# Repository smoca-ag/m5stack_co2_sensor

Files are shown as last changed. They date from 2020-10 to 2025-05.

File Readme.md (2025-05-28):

# Build your own portable, graphing CO₂ sensor

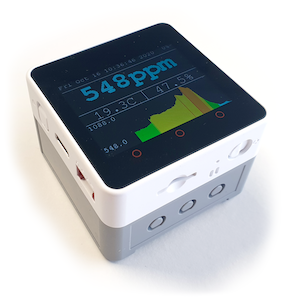
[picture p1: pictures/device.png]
Device The Device


## Motivation

CO₂ levels measured indoors can be used as an indicator of air quality.

Outdoor air has a CO₂ ppm level of 400 ppm. Humans exhale air with 40000 ppm. You can calculate the percentage of exhaust air you are breathing by dividing measured CO₂ level above outdoor by the human exhaust level. Used air might contain aerosols which might contain the corona virus.

High indoor CO₂ levels also have an impact on the cognitive performance of humans.

Smoca AG decided to build this easy to reproduce CO₂ measuring device to help slow the spread of the corona virus in offices.
It supports its users in deciding when ventilating the room begin monitored is advisable. It also raises awareness for the correlation between CO₂ level and air quality.

## Hardware

The following hardware is needed:

| description | cost | link |
| --- | --- | --- |
| Sensirion SCD30 | 54 USD | https://www.digikey.com/en/products/detail/sensirion-ag/SCD30/8445334<br>Switzerland: https://www.bastelgarage.ch/co2-sensor-scd30-sensirion |
| M5 Stack Core2 | 39.9 USD | https://www.digikey.com/en/products/detail/m5stack-technology-co-ltd/K010/13151126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<br>Switzerland: https://www.bastelgarage.ch/m5stack-core2-esp32-iot-entwicklungs-kit |
| M5 Stack Proto Board | 2.95 USD | https://www.digikey.com/en/products/detail/m5stack-technology-co-ltd/M001/10492145<br>Switzerland: https://www.bastelgarage.ch/m5stack-core-development-proto-board |
| M5 Stack PLC Base | 9.95 USD | https://m5stack.com/collections/m5-base/products/plc-proto-industrial-board-module<br>Switzerland: https://www.bastelgarage.ch/m5stack-plc-proto-base-industrial-board |
| M5 Stack Battery (optional) | 7.95 USD | https://www.digikey.com/en/products/detail/m5stack-technology-co-ltd/M002/10492127<br>Switzerland: https://www.bastelgarage.ch/m5stack-battery-module-700mah-fur-esp32-core |

Note: The optional battery increases the battery operation time from 6 to 10 hours.

### Building

|Description | Image
|--- | ---
|1. Power the Core2 module. A factory test application should be loaded. Test the device. |
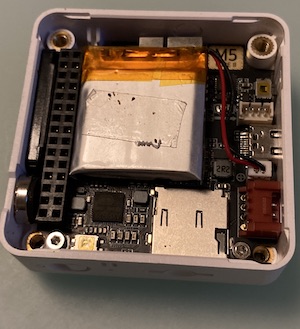
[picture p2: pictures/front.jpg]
Front
|2. Remove the bottom of the Core2 module. Keep the battery there or replace it with the optional bigger one. | 
|3. Remove the PCB from the proto module. |
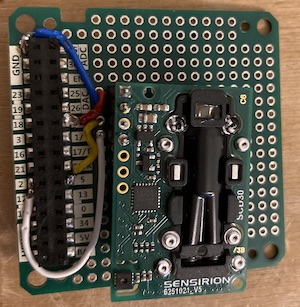
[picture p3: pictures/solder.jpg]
solder
|4. Connect the SCD30 module to the proto module. We used pin headers. | 
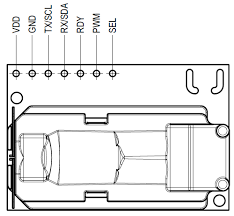
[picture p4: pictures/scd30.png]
scd30
|5. Connect VDD with 3V3, GND with GND, TX/SCL with pin 5 and RX/SDA with pin 2. The other pins don't need to be connected to the proto module. | 
|5. Screw the proto module to the PLC Base |
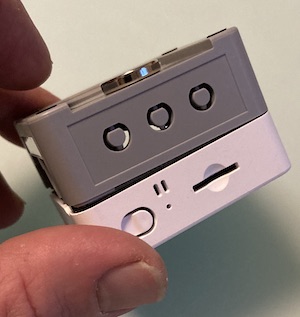
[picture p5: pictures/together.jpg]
together connected
|6. Screw the PLC Base to the Core2 module | 
|7. HW Done, load the software |

## Software

To initialise the device do the following:

1. Install [Platformio IDE](https://platformio.org/platformio-ide) or [PlatformIO Core](https://docs.platformio.org/en/latest/core/installation.html) to use another IDE
2. Open the `co2-sensor` project folder
3. Flash the `main.cpp` script to your M5 Stack Core2 with `pio run -t upload --upload-port {your_device}`. You can see a list of your devices with `pio device list`. Dependencies are installed automatically.

## Features

#### Calibration

The SCD30 can be calibrated manually or automatically. For manual calibration, the device must be placed outdoors for at least five minutes. Then the calibration can be adjusted. Fresh air has a CO₂ concentration of about 400 ppm. To use automatic calibration, the device must have access to fresh air for at least one hour a day.

#### WiFi

To use MQTT, synchronization and update functionality the device must have internet connection. To add WiFi credentials the device opens an access point with a web interface (Default IP is 192.168.4.1). 

#### Data sharing via MQTT

[MQTT](https://mqtt.org/) can be used to send the sensors data to a custom MQTT broker. Server, Port, Topic, Device name, Username and Password can also be configured in the web interface. Each minute the device sends its data in the following format: `{TOPIC}/{CATEGORY} {VALUE}`. Here an example: `sensor/co2 650`.  
Topics are able to have subtopics: `office2/meeting_room1/co2 1100`.  
The following categories are provided by the device: `/co2`, `/humidity`, `/temperature`.

#### Time synchronization

To keep time up to date the device synchronizes with a time server each night between two and three o'clock.

#### Firmware updates

Is a new firmware available, it can manually be updated via WiFi.

#### SNMP

Using SNMP you are able to read the values of the co2, temperature and humidity sensors and also check the battery status of the device:
1. First you have to make sure you have net-snmp installed on your system. You can do this using your package manager or by downloading it from http://www.net-snmp.org/download.html
2. Second you have to find out where your mib files are stored using the command ```net-snmp-config --default-mibdirs```.
3. Then you have to copy the [mib file](./snmp-mib/sensorhub.mib) from ```/snmp-mib/sensorhub.mib``` into one of the listed directories. e.g. ```cp snmp-mib/sensorhub.mib ~/.snmp/mibs```
4. Done that, you can now use snmptable to list the sensors: 
    ```snmptable -m +SENSORHUB-MIB -c public {IP-Address} shSensorTable```
    \
    Which should output the following:
    ```
    SNMP table: SENSORHUB-MIB::shSensorTable

    shSensorName
            SCD30
            BATTERY
   ```
    or to list the measurement values: 
    ```snmptable -m +SENSORHUB-MIB -c public {IP-Address} shMeasurementTable```
    \
    Which should output something like this:
    ```
    SNMP table: SENSORHUB-MIB::shMeasurementTable

    shMeasurementType shMeasurementValue
                co2                  617
        temperature                  207
           humidity                  433
            voltage                  3
    electricCurrent                  276
   ```

## Usage

**Disclaimer This is not a safety device. Always follow the local regulations regarding corona safety. No warranty is provided**
![Device](pictures/flyer.png "Device usage")

### Graphs

- The graphs alway show the last six hours. Every line on the graph represents the measurement of one minute. The last value measured in the given minute is used for the graph.
- To switch between different graphs (temperature / humidity / battery / co2) touch the corresponding value in the display

### microsd

If a microsd card formated with fat is present, a csv file, data.txt will be written every 2 seconds with the timestamp, the co2 level, the humidity, the temperature and the current battery charge.

### CO₂

| level           | color  | description                                                                                               |
| --------------- | ------ | --------------------------------------------------------------------------------------------------------- |
| < 600 ppm       | blue   | outdoor air                                                                                               |
| 600 - 800 ppm   | green  | fresh indoor air                                                                                          |
| 800 - 1000 ppm  | yellow | indoor air, ventilate the room if possible, small possibility of virus transmission                       |
| 1000 - 1400 ppm | orange | used indoor air, ventilate the room, cognition is impacted, possibility of virus transmission             |
| > 1400 ppm      | red    | heavy used indoor air, heavy cognition impact, high possiblity of virus transmission, ventilation needed. |

## Extended uses (no code provided)

- We use it at our office to control a couple of exhaust / inlet pwm computer fans to keep the CO₂ level below 800 ppm.
- We log the measurement results to a influxdb with a grafana dashboard. The grafana instance sends alerts to telegram for CO₂ levels above 800 ppm.

## SCD4x
There is a PCB in the PCB folder for SCD41 Support. The Code Supports transparently SCD40 and SCD30 at the moment.

## Contact

If you have any suggestions for the project feel free to file an issue. If you want to build the device on a bigger scale / have any other development / prototyping needs, feel free to contact us: info@smoca.ch

## License

Copyright (c) 2020 David Gunzinger / smoca AG www.smoca.ch \
Code: GPL v3 \
Text / Graphics / Photographs: CC BY-SA

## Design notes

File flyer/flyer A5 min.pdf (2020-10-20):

# PORTABLE GRAPHING

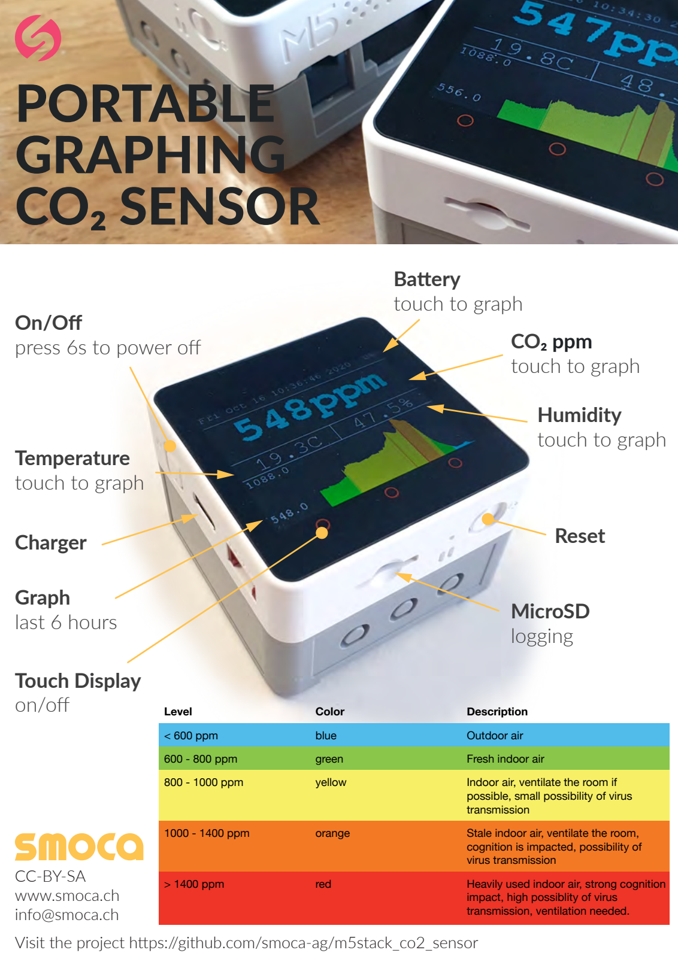
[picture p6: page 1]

# CO₂ SENSOR

## On/Off

## press 6s to power off

## Battery

## touch to graph

## CO₂ ppm

## touch to graph

## Temperature

## touch to graph

## Charger

## Humidity

## touch to graph

## Touch Display

## on/off

## Reset

## MicroSD

## logging

## Graph

## last 6 hours

### Visit the project https://github.com/smoca-ag/m5stack_co2_sensor

### CC-BY-SA www.smoca.ch info@smoca.ch

Level | Color | Description
< 600 ppm | blue | Outdoor air
600 - 800 ppm | green | Fresh indoor air
800 - 1000 ppm | yellow | Indoor air, ventilate the room if possible, small possibility of virus transmission
1000 - 1400 ppm | orange | Stale indoor air, ventilate the room, cognition is impacted, possibility of virus transmission
> 1400 ppm | red | Heavily used indoor air, strong cognition impact, high possiblity of virus transmission, ventilation needed.

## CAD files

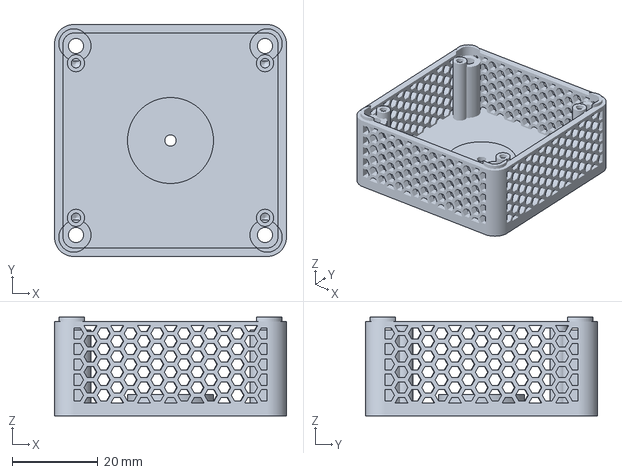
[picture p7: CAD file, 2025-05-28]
case/encasing3-Cut.3mf
54.0 x 54.0 x 23.0 mm

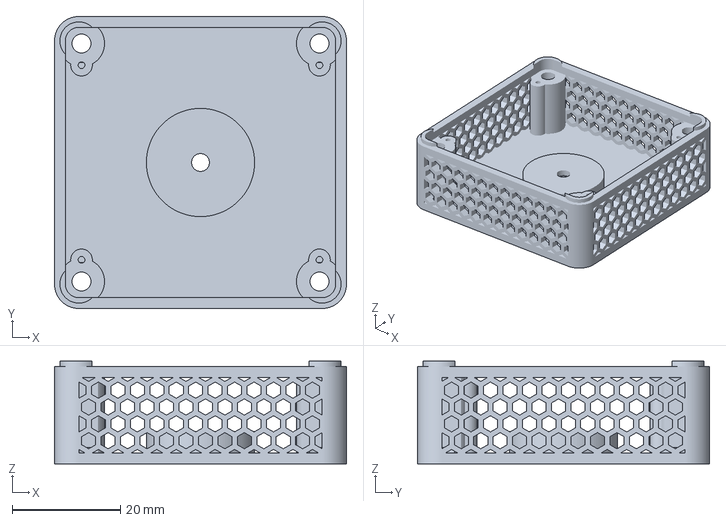
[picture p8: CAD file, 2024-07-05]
case/encasing4-Cut.3mf
54.0 x 54.0 x 19.0 mm

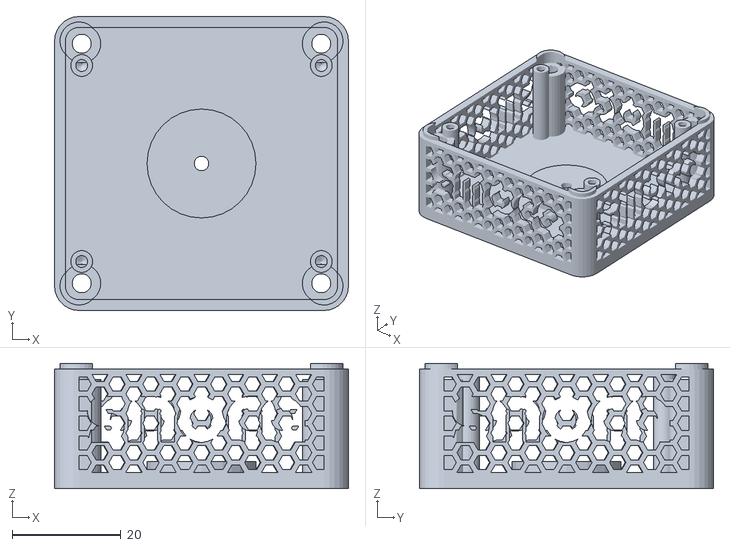
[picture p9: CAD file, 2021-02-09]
case/encasing3_smoca_body.stl
54.0 x 54.0 x 23.0

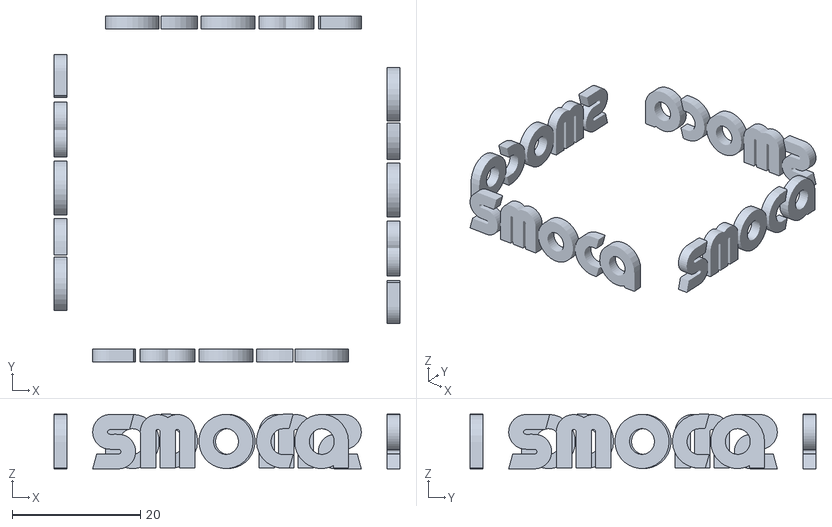
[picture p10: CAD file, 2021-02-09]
case/encasing3_smoca_color.stl
54.0 x 54.0 x 8.55

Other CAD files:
case/encasing4.FCStd
case/encasing3.stl
case/encasing4-Cut.stl

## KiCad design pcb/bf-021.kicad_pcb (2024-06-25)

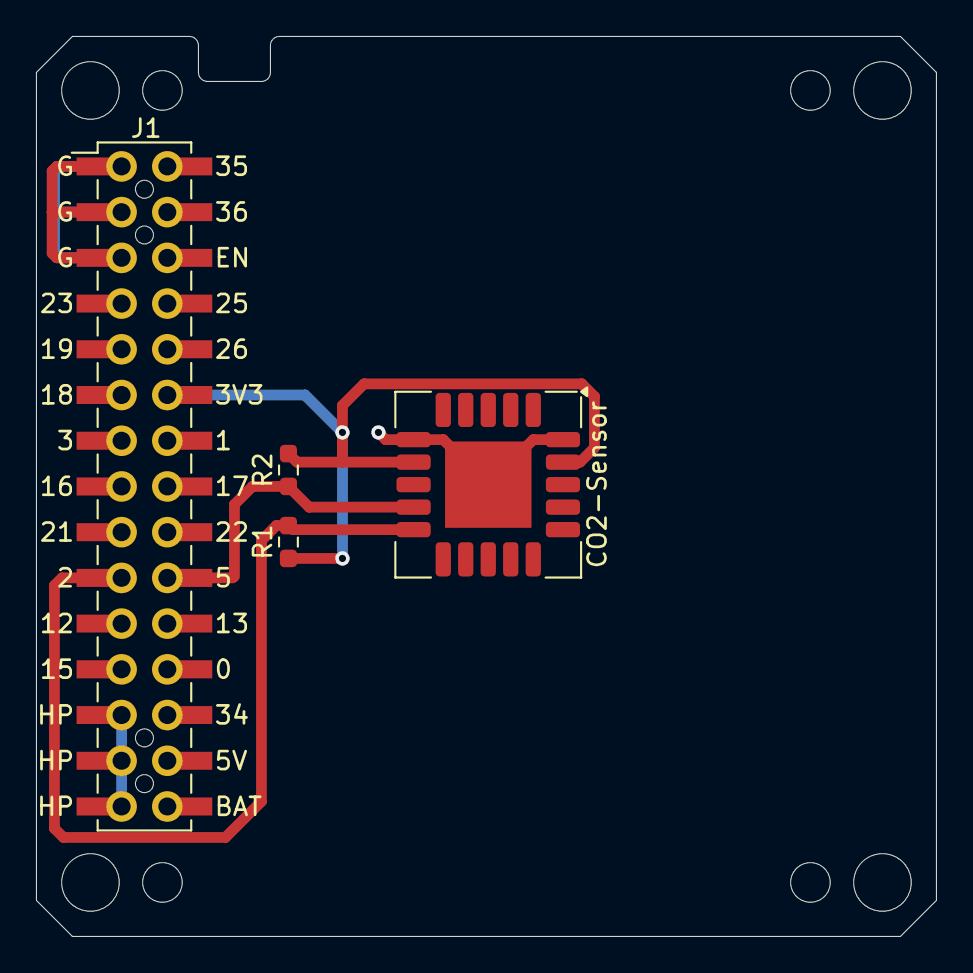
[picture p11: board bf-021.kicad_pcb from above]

Board: 2 copper layers, 50.0 x 50.0 mm, 12 parts (0 on the bottom side), 4 nets.

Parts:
CO2-Sensor: SCD40-D-R2; Sensirion_SCD4x-1EP_10.1x10.1mm_P1.25mm_EP4.8x4.8mm
H1, H2, H3, H4: MountingHole; BF@MountingHole_3.2mm_M3
H5, H6, H7, H8: MountingHole; BF@MountingHole_2.2mm_M2
J1: M-BUS; BF@M5Stack_MBUS
R1, R2: 10k; R_0603_1608Metric_Pad0.98x0.95mm_HandSolder

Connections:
+3V3: CO2-Sensor.7 (VDD), CO2-Sensor.19 (VDD), J1.11, R1.1, R2.2
GND: CO2-Sensor.6 (GND), CO2-Sensor.20 (GND), CO2-Sensor.21 (GND), J1.2, J1.4, J1.6
SDA: CO2-Sensor.9 (SCL), CO2-Sensor.10 (SDA), J1.19, J1.20, R1.2, R2.1
VBUS: J1.26, J1.28, J1.30

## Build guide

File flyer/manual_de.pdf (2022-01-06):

## CO₂ SENSOR Bedienungsanleitung

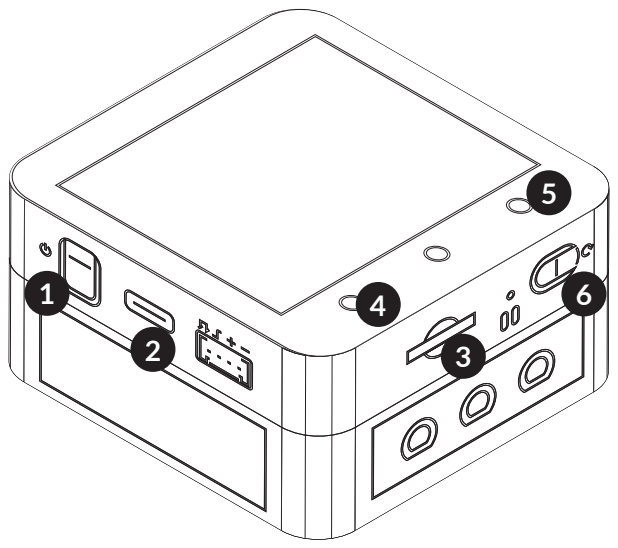
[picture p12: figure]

AN/AUS
Drücken Sie den Knopf 6 Sekunden um das Gerät auszuschalten

LADEN (USB-C)
Laden Sie das Gerät mit dem mitgeliefertem USB Ladekabel oder einem andern kompatiblem USB-C Kabel

MICRO SD-CARD (LOGGING)
Legen Sie eine im FAT formatierte Micro-SD Karte ein um die CO₂ Konzentration-Daten alle 2 Sekunden aufzuzeichnen. Wahlweise wird eine CSV- oder TXT-Datei erstellt.

HOME
Gelangen Sie ins Hauptmenü. Das Display kann hier ausgeschaltet werden.

NAVIGATION
Navigiert durch das Menu

RESET
Startet das System neu.

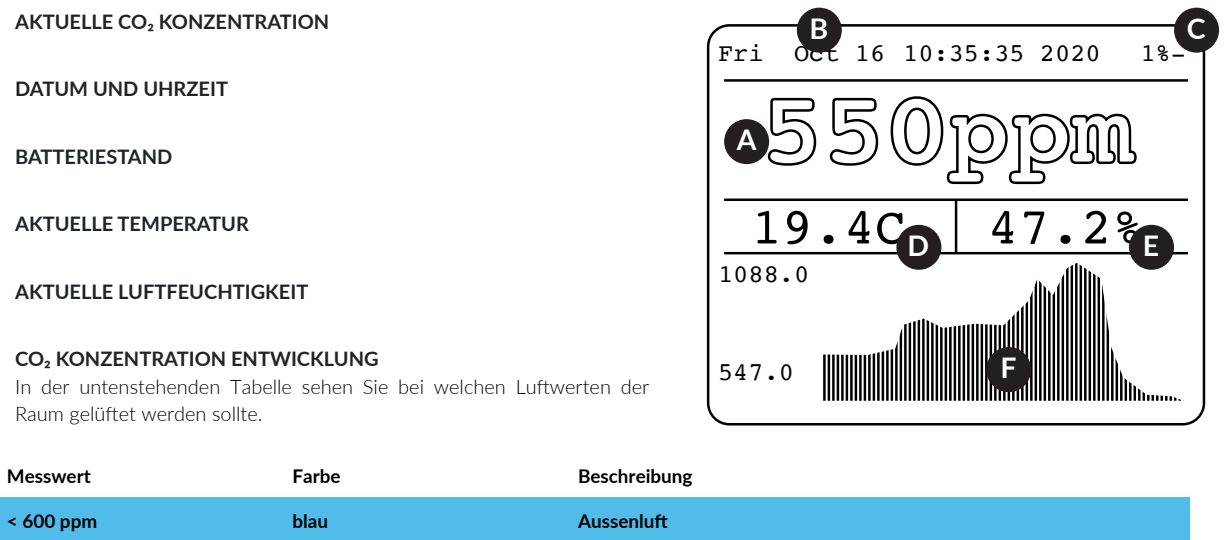
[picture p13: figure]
AKTUELLE CO₂ KONZENTRATION; DATUM UND UHRZEIT; BATTERIESTAND; AKTUELLE TEMPERATUR; AKTUELLE LUFTFEUCHTIGKEIT; CO₂ KONZENTRATION ENTWICKLUNG; Raum gelüftet werden sollte.; Fri Oct 16 10:35:35 2020; 550ppm; Messwert; Farbe; Beschreibung; < 600 ppm; blau; Aussenluft

In der untenstehenden Tabelle sehen Sie bei welchen Luftwerten der

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
KALIBRIEREN
Vor Inbetriebnahme ist es nötig das Gerät zu kalibrieren. Drücken Sie auf den HOME (4) Knopf und wählen Sie eine automatische oder manuelle Kalibration aus:

Automatisch (empfohlen)
Stellen Sie das Gerät täglich für 1h an die frische Luft.
Manuell
Stellen Sie das Gerät für 5min an die frische Luft. Die Kalibration kann manuell mit den Bedienelementen erhöht oder verringert werden. Frischluft hat eine CO₂ Konzentration von ca 400 ppm.
600 - 800 ppm | grün | Frische Innenluft
800 - 1000 ppm | gelb | Innenluft. Raum lüften wenn möglich. Kleine Wahrscheinlichkeit für Virusübertragung.
1000 - 1400 ppm | orange | Abgestandene Innenluft. Raum lüften. Denkleistung wird beeinträchtigt. Virusübertragung möglich.
> 1400 ppm | rot | Stark gebrauchte Innenluft. Lüften notwendig. Hohe Beeinträchtigung der Denkleistung. Hohe Wahrscheinlichkeit für Virusübertragung.

Weitere Informationen unter: https://www.smoca.ch/produkte/co2sensor oder info@smoca.ch Github: https://github.com/smoca-ag/m5stack_co2_sensor

©2021 Smoca AG
Lizenz: Creative Commons BY-SA Der Sensor wurde entwickelt und zur Verfügung gestellt von smoca AG.

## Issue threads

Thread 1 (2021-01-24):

Request for Soldering schematics / wiring diagram

tolkiman, 2021-01-24:
Step 4 simply states "Connect the SCD30 module to the proto module. We used headers."

I would really like to build this project, however its hard to make out which connections to solder and what to connect exactly. Would you be able to supply a simple wiring diagram / soldering schematics? Thanks!

4nd2in, 2021-01-25:
On page of the [datasheet](https://cdn.sparkfun.com/assets/1/a/7/9/9/Sensirion_CO2_Sensors_SCD30_Preliminary-Datasheet.pdf) 6 you can see the pin-out diagram of the scd30. You need to connect VDD with 3V3, GND with GND, TX/SCL with pin 5 and RX/SDA with pin 2. The other pins don't need to be connected to the proto module.

tolkiman, 2021-01-26:
Fantastic, thanks for the support!

Closed 2021-01-26.

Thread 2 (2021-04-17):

Too heavy SW

Kabron287, 2021-04-17:
Your project does not work. How to threw out WiFiManager, MQTT, WEB and all this trash and leave only essential.

> M5Core2 initializing...axp: vbus limit off
axp: gpio1 init
axp: gpio2 init
axp: rtc battery charging enabled
axp: esp32 power voltage was set to 3.35v
axp: lcd backlight voltage was set to 2.80v
axp: lcd logic and sdcard voltage preset to 3.3v
axp: vibrator voltage preset to 2v
touch: FT6336 ready (fw id 0x10 rel 1, lib 0x300E)
OK
Loaded state file.
deserializeJson() failed: InvalidInput
cgw4Q9da
Setting time: Fri Jun 30 20:49:34 2000
The current date/time in Zuerich is: Fri Jun 30 22:49:34 2000Initializing SD card...
File already exists
WiFi off status: 6
Failed to obtain time
we are to slow:5019
Message appended
Guru Meditation Error: Core  1 panic'ed (StoreProhibited). Exception was unhandled.

Kabron287, 2021-04-17:
Problem was in my sensor driver.
I use  T6703.

pfy, 2021-04-17:
Hi

The NTP Code has a bug as well. If the device does not have the correct time, it might busy loop the ntp code. The we are to slow:5019 message confirms this -> we will push an update next week.

isn't the T6703 more expensive than the sensirion part ? The sensirion costs about 50 CHF and the T6703 about 100 CHF ?

best regards

David Gunzinger
CTO, Co-Founder

Smoca AG ǀ Technoparkstrasse 2 ǀ 8406 Winterthur
G: +41 52 508 59 57
M: ***@***.***
W: www.smoca.ch

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

Kabron287, 2021-04-17:
Thanks for answer/
About 25 CHF on aliexpress.

Closed 2021-04-17.

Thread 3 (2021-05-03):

Make battery size configurable

tobru, 2021-05-03:
When using the bigger battery the display of the available battery percentage isn't calculated correctly. Therefore it would make sense to be able to configure the battery size.

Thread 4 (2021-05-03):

Support MQTT TLS connection

tobru, 2021-05-03:
MQTT can currently only be used with plain TCP connection. My MQTT broker is only reachable via TLS (port 8883). It would be cool if this project would support MQTT TLS connections.

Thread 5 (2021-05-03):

Parts ordering via bastelgarage.ch

tobru, 2021-05-03:
This issue is a FYI issue, can be closed any time: The parts needed for this project are available at bastelgarage.ch, which is easy for Swiss people. Maybe you want to link to it from the README. Disclaimer: I'm not affiliated with bastelgarage.ch, just a fan of them (and this project).

AlfMueller, 2021-08-13:
This issue is a FYI issue, can be closed any time:
add Link for 3d Print Backcover sourcefile on thingiverse:
https://www.thingiverse.com/thing:4651700

marcelstoer, 2021-08-14:
This is actually OT but @AlfMueller did you find the case on Thingiverse more useful then the one in this repository at https://github.com/smoca-ag/m5stack_co2_sensor/blob/main/case/encasing3.stl?

Closed 2021-08-14.

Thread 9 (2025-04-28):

Support the SCD4x sensors

marcelstoer, 2025-04-28:
(This is a kind-of note to self as I plan on adding this)

Support the SCD4x sensors by using their official driver from https://registry.platformio.org/libraries/sensirion/Sensirion%20I2C%20SCD4x

pfy, 2025-05-28:
we already did that and even have a sample pcb inside the pcb folder. Please Note: The magnet seems to interfere with the mems microphone inside the SCD40, especially during attaching and detaching.

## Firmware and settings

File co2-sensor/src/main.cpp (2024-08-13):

/*
 * This file is part of the co2sensor distribution (https://github.com/xxxx or http://xxx.github.io).
 * Copyright (c) 2020 David Gunzinger / smoca AG.
 *
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
 * You should have received a copy of the GNU General Public License
 * along with this program. If not, see <http://www.gnu.org/licenses/>.
 */

#include <main.h>
#include <lwip/apps/snmp.h>
#include <sensorhub-mib.h>

static const struct snmp_mib *mibs[] = {
    &sensorhub_mib};

struct state state;
struct graph graph;

// background, text, outline
ButtonColors offWhite = {BLACK, WHITE, WHITE};
ButtonColors onWhite = {WHITE, BLACK, WHITE};
ButtonColors offCyan = {BLACK, CYAN, CYAN};
ButtonColors onCyan = {CYAN, BLACK, CYAN};
ButtonColors offRed = {BLACK, RED, RED};
ButtonColors onRed = {RED, BLACK, RED};
ButtonColors offGreen = {BLACK, GREEN, GREEN};
ButtonColors onGreen = {GREEN, BLACK, GREEN};

// x, y, w, h, rot, txt, off col, on color, txt pos, x-offset, y-offset, corner radius
Button batteryButton(240, 0, 80, 40);
Button co2Button(0, 26, 320, 88);

Button midLeftButton(-2, 104, 163, 40, false, "midLeft", offWhite, onWhite, BUTTON_DATUM, 0, 0, 0);
Button midRightButton(161, 104, 164, 40, false, "midRight", offWhite, onWhite, BUTTON_DATUM, 0, 0, 0);

Button toggleAutoCalButton(15, 175, 130, 50, false, "Auto Cal: OFF", offRed, onRed);
Button submitCalibrationButton(175, 175, 130, 50, false, "Calibrate", offCyan, onCyan);

Button toggleWiFiButton(15, 175, 130, 50, false, "OFF", offRed, onRed);
Button resetWiFiButton(175, 175, 130, 50, false, "Reset", offCyan, onCyan);

Button syncTimeButton(15, 175, 290, 50, false, "Sync Time", offCyan, onCyan);
Button rotateScreenButton(15, 175, 290, 50, false, "Rotate", offCyan, onCyan);

TFT_eSprite DisbuffHeader = TFT_eSprite(&M5.Lcd);
TFT_eSprite DisbuffValue = TFT_eSprite(&M5.Lcd);
TFT_eSprite DisbuffGraph = TFT_eSprite(&M5.Lcd);
TFT_eSprite DisbuffBody = TFT_eSprite(&M5.Lcd);

uint64_t chipid = ESP.getEfuseMac(); // The chip ID is essentially its MAC address(length: 6 bytes).
uint16_t chip = (uint16_t)(chipid >> 32);


String ssid = "smoca CO2-" + String(chip, HEX) + String((uint32_t)chipid, HEX);
IPAddress stationIP = IPAddress(0, 0, 0, 0);
IPAddress gatewayIP = IPAddress(192, 168, 2, 1);
IPAddress netMask = IPAddress(255, 255, 255, 0);

IPAddress dns1IP = gatewayIP;
IPAddress dns2IP = IPAddress(8, 8, 8, 8);

IPAddress APStaticIP = IPAddress(192, 168, 100, 1);
IPAddress APStaticGW = IPAddress(192, 168, 100, 1);
IPAddress APStaticSN = IPAddress(255, 255, 255, 0);

AsyncWebServer webServer(80);

SCD30 airSensorSCD30;
SCD4x airSensorSCD40;
void* currentAirSensor;

WM_Config WM_config;
WiFi_STA_IPConfig WM_STA_IPconfig;

AsyncDNSServer dnsServer;
String Router_SSID;
String Router_Pass;

ESPAsync_WiFiManager *asyncWifiManager;

ESPAsync_WMParameter *mqttServer;
ESPAsync_WMParameter *mqttPort;
ESPAsync_WMParameter *mqttTopic;
ESPAsync_WMParameter *mqttDevice;
ESPAsync_WMParameter *mqttUser;
ESPAsync_WMParameter *mqttPassword;

WiFiClient client;
PubSubClient mqtt(client);

// MQTT discovery data configurations
struct discoveryDeviceConfig deviceConfig;
struct discoveryConfig co2Config;
struct discoveryConfig humidityConfig;
struct discoveryConfig temperatureConfig;
struct discoveryConfig batteryConfig;

// MQTT Discovery unique identifiers
String identifier = String(chip, HEX) + String((uint32_t)chipid, HEX);
String co2DiscoveryIdentifier = identifier + "-1";
String humidityDiscoveryIdentifier = identifier + "-2";
String temperatureDiscoveryIdentifier = identifier + "-3";
String batteryDiscoveryIdentifier = identifier + "-4";
String identifiers =
    co2DiscoveryIdentifier + ", " +
    humidityDiscoveryIdentifier + ", " +
    temperatureDiscoveryIdentifier + ", " +
    batteryDiscoveryIdentifier;

// statistics
unsigned long cycle;
int target_fps = 20;
int frame_duration_ms = 1000 / target_fps;
float my_nan;

void setup()
{
    Serial.println("Start Setup.");
    my_nan = sqrt(-1);

    M5.begin();

    // Initialize SPIFFS
    if (!SPIFFS.begin(true))
    {
        Serial.println("An Error has occurred while mounting SPIFFS");
        return;
    }

    loadStateFile();
    if (state.is_screen_rotated)
    {
        M5.BtnA.set(10, -40, 110, 40, false);
        M5.BtnB.set(130, -40, 70, 40, false);
        M5.BtnC.set(230, -40, 80, 40, false);
        M5.Lcd.setRotation(3);
    }

    M5.Lcd.setSwapBytes(true);
    M5.Lcd.pushImage(96, 96, 128, 32, smoca_logo);

    M5.Axp.SetCHGCurrent(AXP192::kCHG_280mA);
    M5.Axp.EnableCoulombcounter();
    M5.Axp.SetLed(M5.Axp.isACIN() ? 1 : 0);

    ssid.toUpperCase();
    mqtt.setBufferSize(512);

    loadMQTTConfig();
    setPassword(&state);
    setDisplayPower(true);
    setTimeFromRtc();
    printTime();
    createSprites();
    hideButtons();

    if (!state.next_time_sync.tm_year)
    {
        state.next_time_sync.tm_year = 1900;
        state.next_time_sync.tm_hour = TIME_SYNC_HOUR;
        state.next_time_sync.tm_min = TIME_SYNC_MIN;
    }

    for (int i = 0; i < GRAPH_UNITS; i++)
    {
        graph.temperature[i] = my_nan;
        graph.co2[i] = my_nan;
        graph.humidity[i] = my_nan;
        graph.batteryMah[i] = my_nan;
    }

    initSD();
    initAirSensor();
    initAsyncWifiManager(&state);
    initSTAIPConfigStruct(WM_STA_IPconfig);
    initDeviceDiscoveryConfig(&deviceConfig);
    initCo2DiscoveryConfig(&co2Config);
    initHumidityDiscoveryConfig(&humidityConfig);
    initTemperatureDiscoveryConfig(&temperatureConfig);
    initBatteryDiscoveryConfig(&batteryConfig);

    if (mqtt.connected()) {
        sendMQTTDiscoveryMessages(
            &co2Config,
            &humidityConfig,
            &temperatureConfig,
            &batteryConfig
        );
    }

#if LWIP_SNMP
    const struct snmp_obj_id device_enterprise_oid = {8, {1, 3, 6, 1, 4, 1, 58049, 1}};
    snmp_set_device_enterprise_oid(&device_enterprise_oid);

    snmp_set_mibs(mibs, LWIP_ARRAYSIZE(mibs));
    snmp_init();
#endif /* LWIP_SNMP */

    cycle = 0;
    Serial.print(state.is_wifi_activated ? "WiFi on" : "WiFi off");
    Serial.println(" status: " + (String)WiFi.status());
}

extern "C" int get_measurement(u32_t sensor_id, u32_t measurement_type)
{
    switch (sensor_id)
    {
    case 1:
        switch (measurement_type)
        {
        case CO2_PPM_MEASUREMENT:
            return state.co2_ppm;
        case TEMPERATURE_MEASUREMENT:
            return state.temperature_celsius;
        case HUMIDITY_MEASUREMENT:
            return state.humidity_percent;
        default:
            return 0;
        }
        break;
    case 2:
        switch (measurement_type)
        {
        case BATTERY_VOLTAGE_MEASUREMENT:
            return state.battery_voltage;
        case BATTERY_CURRENT_MEASUREMENT:
            return state.battery_current;
        default:
            return 0;
        }
        break;
    default:
        return 0;
    }
}

void loop()
{
    unsigned long start = millis();
    struct state oldstate;
    memcpy(&oldstate, &state, sizeof(struct state));

    M5.update();

    updateTouch(&state);
    updateTime(&state);
    updateBattery(&state);
    updateCo2(&state);
    updateGraph(&oldstate, &state);
    updateLed(&oldstate, &state);
    updateTimeState(&oldstate, &state);
    updateMQTT(&state);

    saveStateFile(&oldstate, &state);

    handleWifiMqtt(&oldstate, &state);

    updateScreenRotation(&oldstate, &state);
    drawScreen(&oldstate, &state);

    handleConfigPortal(&oldstate, &state);
    syncData(&state);
    handleFirmware(&oldstate, &state);
    writeSsd(&state);

    cycle++;
    unsigned long duration = millis() - start;
    if (duration < frame_duration_ms)
    {
        delay(frame_duration_ms - duration);
    }
    else
    {
        Serial.println("we are to slow:" + String(duration));
    }
}

String randomPassword(int length)
{
    char alphanum[63] = "0123456789ABCDEFGHIJKLMNOPQRSTUVWXYZabcdefghijklmnopqrstuvwxyz";
    const int strLen = sizeof(alphanum);
    String pwd;
    srand(millis());

    for (int i = 0; i < length; i++)
    {
        pwd += alphanum[rand() % strLen];
    }

    return pwd;
}

void loadStateFile()
{
    File file = SPIFFS.open(STATE_FILENAME, "r");

    if (file)
    {
        String battery_string = file.readStringUntil('\n');
        String auto_cal_string = file.readStringUntil('\n');
        String calibration_string = file.readStringUntil('\n');
        String is_wifi_activated = file.readStringUntil('\n');
        String is_screen_rotated = file.readStringUntil('\n');
        String password = file.readStringUntil('\n');
        String newest_version = file.readStringUntil('\n');
        file.close();

        if (battery_string.length() > 0)
        {
            state.battery_capacity = battery_string.toFloat();
        }
        if (state.battery_capacity == 0)
        {
            state.battery_capacity = 700;
        }

        state.auto_calibration_on = auto_cal_string == "1" ? true : false;
        state.calibration_ppm_value = calibration_string.toInt() < 400 ? 400 : calibration_string.toInt();
        state.is_wifi_activated = is_wifi_activated == "1" ? true : false;
        state.is_screen_rotated = is_screen_rotated == "1" ? true : false;
        STRCPY(state.password, password.c_str());
        STRCPY(state.newest_version, newest_version.c_str());
        Serial.println("Loaded state file.");
        if (mqtt.connected()) {
            sendMQTTDiscoveryMessages(
                &co2Config,
                &humidityConfig,
                &temperatureConfig,
                &batteryConfig
            );
        }
    }
    else
    {
        Serial.println("state file could not be read.");
    }
}

void saveStateFile(struct state *oldstate, struct state *state)
{
    if (state->battery_capacity == oldstate->battery_capacity &&
        state->auto_calibration_on == oldstate->auto_calibration_on &&
        state->calibration_ppm_value == oldstate->calibration_ppm_value &&
        state->is_wifi_activated == oldstate->is_wifi_activated &&
        state->is_screen_rotated == oldstate->is_screen_rotated &&
        strncmp(state->password, oldstate->password, MAX_CP_PASSWORD_LEN) == 0 &&
        strncmp(state->newest_version, oldstate->newest_version, VERSION_NUMBER_LEN) == 0)
    {
        return;
    }

    File f = SPIFFS.open(STATE_FILENAME, "w");
    f.print(
        (String)state->battery_capacity + "\n" +
        (String)state->auto_calibration_on + "\n" +
        (String)state->calibration_ppm_value + "\n" +
        (state->is_wifi_activated ? "1" : "0") + "\n" +
        (state->is_screen_rotated ? "1" : "0") + "\n" +
        (String)state->password + "\n" +
        (String)state->newest_version + "\n");
    f.close();
    Serial.println("State file saved");

    if (mqtt.connected()) {
        sendMQTTDiscoveryMessages(
            &co2Config,
            &humidityConfig,
            &temperatureConfig,
            &batteryConfig
        );
    }
}

void initSTAIPConfigStruct(WiFi_STA_IPConfig &in_WM_STA_IPconfig)
{
    in_WM_STA_IPconfig._sta_static_ip = stationIP;
    in_WM_STA_IPconfig._sta_static_gw = gatewayIP;
    in_WM_STA_IPconfig._sta_static_sn = netMask;
#if USE_CONFIGURABLE_DNS
    in_WM_STA_IPconfig._sta_static_dns1 = dns1IP;
    in_WM_STA_IPconfig._sta_static_dns2 = dns2IP;
#endif
}

void initAsyncWifiManager(struct state *state)
{
    asyncWifiManager = new ESPAsync_WiFiManager(&webServer, &dnsServer);
    asyncWifiManager->setDebugOutput(false);
    asyncWifiManager->setMinimumSignalQuality(-1);
    asyncWifiManager->setConfigPortalChannel(0);
    asyncWifiManager->setConfigPortalTimeout(120);
    asyncWifiManager->setAPCallback(accessPointCallback);
    asyncWifiManager->setSaveConfigCallback(configPortalCallback);

    mqttServer = new ESPAsync_WMParameter(MQTT_SERVER_Label, "MQTT Server *", state->mqttServer, MQTT_SERVER_LEN - 1);
    mqttPort = new ESPAsync_WMParameter(MQTT_SERVERPORT_Label, "MQTT Serverport *", state->mqttPort, MQTT_PORT_LEN - 1);
    mqttTopic = new ESPAsync_WMParameter(MQTT_TOPIC_Label, "MQTT Topic *", state->mqttTopic, MQTT_TOPIC_LEN - 1);
    mqttDevice = new ESPAsync_WMParameter(MQTT_DEVICENAME_Label, "MQTT unique device name", state->mqttDevice,
                                          MQTT_DEVICENAME_LEN - 1);
    mqttUser = new ESPAsync_WMParameter(MQTT_USERNAME_Label, "MQTT Username", state->mqttUser, MQTT_USERNAME_LEN - 1);
    mqttPassword = new ESPAsync_WMParameter(MQTT_KEY_Label, "MQTT Password", state->mqttPassword, MQTT_KEY_LEN - 1);

    asyncWifiManager->addParameter(mqttServer);
    asyncWifiManager->addParameter(mqttPort);
    asyncWifiManager->addParameter(mqttTopic);
    asyncWifiManager->addParameter(mqttDevice);
    asyncWifiManager->addParameter(mqttUser);
    asyncWifiManager->addParameter(mqttPassword);

#if !USE_DHCP_IP
#if USE_CONFIGURABLE_DNS
    // Set static IP, Gateway, Subnetmask, DNS1 and DNS2. New in v1.0.5
    asyncWifiManager->setSTAStaticIPConfig(stationIP, gatewayIP, netMask, dns1IP, dns2IP);
#else
    // Set static IP, Gateway, Subnetmask, Use auto DNS1 and DNS2.
    asyncWifiManager->setSTAStaticIPConfig(stationIP, gatewayIP, netMask);
#endif
#endif
}

void initSD()
{
    SD.begin();
    if (!SD.begin())
    {
        Serial.println("Card Mount Failed");
    }

    uint8_t cardType = SD.cardType();
    if (cardType == CARD_NONE)
    {
        Serial.println("No SD card attached");
    }

    Serial.println("Initializing SD card...");
    if (!SD.begin())
    {
        Serial.println("ERROR - SD card initialization failed!");
    }

    // If the data.txt file doesn't exist
    // Create a file on the SD card and write the data labels
    File file = SD.open("/data.txt");
    if (!file)
    {
        Serial.println("File doens't exist");
        Serial.println("Creating file...");
        writeFile(SD, "/data.txt", "Date, Co2 (ppm), Temperature, Humidity, Battery Charge \r\n");
    }
    else
    {
        Serial.println("File already exists");
    }

    file.close();
}

void initAirSensor()
{
    Wire.begin(G32, G33);

    if (airSensorSCD30.begin(Wire, state.auto_calibration_on) == true)
    {
        currentAirSensor = &airSensorSCD30;
        Serial.println("Air sensor SCD30 detected.");
        airSensorSCD30.setTemperatureOffset(state.temp_offset);
        airSensorSCD30.setAltitudeCompensation(440);
    } 
    else if (airSensorSCD40.begin(Wire, state.auto_calibration_on) == true)
    {
        currentAirSensor = &airSensorSCD40;
        Serial.println("Air sensor SCD4x detected.");
        airSensorSCD40.setTemperatureOffset(state.temp_offset);
        airSensorSCD40.setSensorAltitude(440);
        airSensorSCD40.startPeriodicMeasurement();
    } 
    else 
    {
        DisbuffValue.setTextColor(RED);
        Serial.println("Air sensor not detected. Please check wiring. Freezing...");
        DisbuffValue.drawString("Air sensor not detected.", 0, 0);
        DisbuffValue.drawString("Please check wiring.", 0, 25);
        DisbuffValue.drawString("Freezing.", 0, 50);
        DisbuffValue.pushSprite(0, 26);
        while (1)
        {
            delay(1000);
        }
    }
}

void initDeviceDiscoveryConfig(struct discoveryDeviceConfig *config)
{
    String deviceName = state.mqttDevice ? state.mqttDevice : "CO2 Sensor " + identifier;
    String deviceModel = (String)HOMEASSISTANT_DEVICE_MODEL_Value;
    String manufacturer = (String)HOMEASSISTANT_DEVICE_MANUFACTURER_Value;

    STRCPY(config->identifiers, identifiers.c_str());
    STRCPY(config->name, deviceName.c_str());
    STRCPY(config->model, deviceModel.c_str());
    STRCPY(config->manufacturer, manufacturer.c_str());
}

void initDiscoveryValueConfig(
    struct discoveryConfig *config,
    String configurationTopic,
    String uniqueId,
    String stateTopic,
    String name,
    String topic,
    String unitOfMeasure,
    String valueTemplate,
    String deviceClass
)
{
    config->device = deviceConfig;
    STRCPY(config->configTopic, configurationTopic.c_str());
    STRCPY(config->uniqueId, uniqueId.c_str());
    STRCPY(config->name, name.c_str());
    STRCPY(config->stateTopic, topic.c_str());
    STRCPY(config->unitOfMeasure, unitOfMeasure.c_str());
    STRCPY(config->valueTemplate, valueTemplate.c_str());
    STRCPY(config->deviceClass, deviceClass.c_str());
}

void initCo2DiscoveryConfig(struct discoveryConfig *config)
{
    String configurationTopic =
        (String)TOPIC_DISCOVERY +
        co2DiscoveryIdentifier +
        (String)TOPIC_CO2 +
        (String)TOPIC_CONFIG;
    String stateTopic = state.mqttTopic + (String)TOPIC_STATE;
    String name = "CO2";
    String topic = state.mqttTopic + (String)TOPIC_STATE;
    String unitOfMeasure = "ppm";
    String valueTemplate = "{{ value_json.carbon_dioxide }}";
    String deviceClass = "carbon_dioxide";

    initDiscoveryValueConfig(
        config,
        configurationTopic,
        co2DiscoveryIdentifier,
        stateTopic,
        name,
        topic,
        unitOfMeasure,
        valueTemplate,
        deviceClass
    );
}

void initHumidityDiscoveryConfig(struct discoveryConfig *config)
{
    String configurationTopic =
        (String)TOPIC_DISCOVERY +
        humidityDiscoveryIdentifier +
        (String)TOPIC_HUMIDITY +
        (String)TOPIC_CONFIG;
    String stateTopic = state.mqttTopic + (String)TOPIC_STATE;
    String name = "Humidity";
    String topic = state.mqttTopic + (String)TOPIC_STATE;
    String unitOfMeasure = "%";
    String valueTemplate = "{{ value_json.humidity }}";
    String deviceClass = "humidity";
    
    initDiscoveryValueConfig(
        config,
        configurationTopic,
        humidityDiscoveryIdentifier,
        stateTopic,
        name,
        topic,
        unitOfMeasure,
        valueTemplate,
        deviceClass
    );
}

void initTemperatureDiscoveryConfig(struct discoveryConfig *config)
{
    String configurationTopic =
        (String)TOPIC_DISCOVERY +
        temperatureDiscoveryIdentifier +
        (String)TOPIC_TEMPERATURE +
        (String)TOPIC_CONFIG;
    String stateTopic = state.mqttTopic + (String)TOPIC_STATE;
    String name = "Temperature";
    String topic = state.mqttTopic + (String)TOPIC_STATE;
    String unitOfMeasure = "°C";
    String valueTemplate = "{{ value_json.temperature }}";
    String deviceClass = "temperature";

    initDiscoveryValueConfig(
        config,
        configurationTopic,
        temperatureDiscoveryIdentifier,
        stateTopic,
        name,
        topic,
        unitOfMeasure,
        valueTemplate,
        deviceClass
    );
}

void initBatteryDiscoveryConfig(struct discoveryConfig *config)
{
    String configurationTopic =
        (String)TOPIC_DISCOVERY +
        batteryDiscoveryIdentifier +
        (String)TOPIC_BATTERY +
        (String)TOPIC_CONFIG;
    String stateTopic = state.mqttTopic + (String)TOPIC_STATE;
    String name = "Battery";
    String topic = state.mqttTopic + (String)TOPIC_STATE;
    String unitOfMeasure = "°C";
    String valueTemplate = "{{ value_json.battery }}";
    String deviceClass = "battery";

    initDiscoveryValueConfig(
        config,
        configurationTopic,
        batteryDiscoveryIdentifier,
        stateTopic,
        name,
        topic,
        unitOfMeasure,
        valueTemplate,
        deviceClass
    );
}
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

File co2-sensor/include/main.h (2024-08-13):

#define VERSION_NUMBER "1.1.9"
#define VERSION_NUMBER_LEN 8
#define FIRMWARE_SERVER "co2-sensor-firmware.smoca.ch"
#define REMOTE_VERSION_FILE "/version.json"
#define REMOTE_FIRMWARE_FILE "/firmware.bin"

#define _ESPASYNC_WIFIMGR_LOGLEVEL_ 0

#define GRAPH_UNITS 240

#define NUM_WIFI_CREDENTIALS 2
#define MAX_SSID_LEN 32
#define MAX_PW_LEN 64
#define MIN_AP_PASSWORD_SIZE 8
#define USE_DHCP_IP true
#define USE_CONFIGURABLE_DNS true

#define CP_PASSWORD_GENERATION_LEN 8
#define MAX_CP_PASSWORD_LEN 16

#define TIME_SYNC_HOUR 2
#define TIME_SYNC_MIN rand() % 60

#define STATE_FILENAME "/state"
#define MQTT_FILENAME "/mqtt.json"
#define CONFIG_FILENAME "/wifi_config"

#define TOPIC_DISCOVERY "homeassistant/sensor/"
#define TOPIC_CO2 "/co2"
#define TOPIC_HUMIDITY "/humidity"
#define TOPIC_TEMPERATURE "/temperature"
#define TOPIC_BATTERY "/battery"
#define TOPIC_CONFIG "/config"
#define TOPIC_STATE "/state"

#define HOMEASSISTANT_UNIQUE_ID_Label "unique_id"
#define HOMEASSISTANT_NAME_Label "name"
#define HOMEASSISTANT_STATE_TOPIC_Label "state_topic"
#define HOMEASSISTANT_UNIT_OF_MEASURE_Label "unit_of_measure"
#define HOMEASSISTANT_VALUE_TEMPLATE_Label "value_template"
#define HOMEASSISTANT_DEVICE_Label "device"
#define HOMEASSISTANT_DEVICE_IDENTIFIERS_Label "identifiers"
#define HOMEASSISTANT_DEVICE_NAME_Label "name"
#define HOMEASSISTANT_DEVICE_MODEL_Label "model"
#define HOMEASSISTANT_DEVICE_MANUFACTURER_Label "manufacturer"
#define HOMEASSISTANT_DEVICE_CLASS_Label "device_class"

#define HOMEASSISTANT_STATE_CO2_Label "carbon_dioxide"
#define HOMEASSISTANT_STATE_HUMIDITY_Label "humidity"
#define HOMEASSISTANT_STATE_TEMPERATURE_Label "temperature"
#define HOMEASSISTANT_STATE_BATTERY_Label "battery"

#define HOMEASSISTANT_DEVICE_MODEL_Value "Smoca CO2 Sensor"
#define HOMEASSISTANT_DEVICE_MANUFACTURER_Value "Smoca AG"

#define MQTT_SERVER_Label "MQTT_SERVER_Label"
#define MQTT_SERVERPORT_Label "MQTT_SERVERPORT_Label"
#define MQTT_DEVICENAME_Label "MQTT_DEVICENAME_Label"
#define MQTT_TOPIC_Label "MQTT_TOPIC_Label"
#define MQTT_USERNAME_Label "MQTT_USERNAME_Label"
#define MQTT_KEY_Label "MQTT_KEY_Label"

#define MQTT_SERVER_LEN 64
#define MQTT_PORT_LEN 8
#define MQTT_DEVICENAME_LEN 24
#define MQTT_TOPIC_LEN 64
#define MQTT_USERNAME_LEN 24
#define MQTT_KEY_LEN 32

#define DISCOVERY_IDENTIFIERS_LEN 72
#define DISCOVERY_DEVICE_MODEL_NAME_LEN 24
#define DISCOVERY_DEVICE_MANUFACTURER_NAME_LEN 16
#define DISCOVERY_UNIQUE_ID_LEN 16
#define DISCOVERY_DEVICE_NAME_CLASS_LEN 32
#define DISCOVERY_TOPIC_LEN 72
#define DISCOVERY_VALUE_TEMPLATE_LEN 32
#define DISCOVERY_UNIT_OF_MEASURE_LEN 8

#define WIFI_SCAN_INTERVAL 5000L
#define WIFI_CONNECT_TIMEOUT 5000L
#define MQTT_INTERVAL 2000L
#define MQTT_PUBLISH_INTERVAL 60000L
#define STRCPY(dst, src) if (strlcpy(dst, src, sizeof(dst)) >= sizeof(dst)) { Serial.println("not enugh space in dst for src"); } 

// hardware
#include <m5stack_core2/pins_arduino.h>
#include <Arduino.h>
#include <M5Core2.h>
#include <SparkFun_SCD30_Arduino_Library.h>
#include <SparkFun_SCD4x_Arduino_Library.h>

// memory
#include <FS.h>
#include <SD.h>
#include <SPI.h>
#include <sys/time.h>
#include <SPIFFS.h>

// WiFi AccessPoint and ConfigPortal
#include <WiFi.h>
#include <ESPAsync_WiFiManager.h>
#include <ArduinoJson.h>

// firmware update
#include <WiFiClient.h>
#include <HTTPClient.h>
#include <Update.h>

// mqtt
#include <PubSubClient.h>

#include <smoca_logo.h>

#include <set>
typedef struct
{
    char wifi_ssid[MAX_SSID_LEN];
    char wifi_pw[MAX_PW_LEN];
} WiFiCredentials;

typedef struct
{
    String wifi_ssid;
    String wifi_pw;
} WiFiCredentialsString;

typedef struct
{
    WiFiCredentials WiFi_Creds[NUM_WIFI_CREDENTIALS];
} WM_Config;

enum graphMode
{
    graphModeCo2,
    graphModeTemperature,
    graphModeHumidity,
    graphModeBatteryMah,
    graphModeLogo
};

enum menuMode
{
    menuModeGraphs,
    menuModeCalibrationPpmSettings,
    menuModeCalibrationTempSettings,
    menuModeCalibrationPpmAlert,
    menuModeCalibrationTempAlert,
    menuModeWiFiSettings,
    menuModeMQTTSettings,
    menuModeTimeSettings,
    menuModeUpdateSettings,
    menuModeRotationSettings
};

enum info
{
    infoCalSuccess,
    infoConfigPortalCredentials,
    infoWiFiConnected,
    infoWiFiFailed,
    infoWiFiLost,
    infoTimeSyncSuccess,
    infoTimeSyncFailed,
    infoUpdateFailed,
    infoEmpty
};

enum connectionState
{
    WiFi_down_MQTT_down = 0,
    WiFi_scan_MQTT_down = 1,
    WiFi_starting_MQTT_down = 2,
    WiFi_up_MQTT_down = 3,
    WiFi_up_MQTT_starting = 4,
    WiFi_up_MQTT_up = 5
};
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

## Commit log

2020-10-18 5.5 temperature offset
2020-10-21 comment about esp32 development version
2021-01-04 draw graph after menu switch
2021-01-04 set min and max for forced calibration
2021-01-04 showing current co2 offset in calibration menu
2021-01-05 auto calibration is now saved in a file
2021-01-06 added persistent state for battery and calibration
2021-01-12 Added WiFi UI, updated Buttons
2021-01-18 added platformio project
    [default_16MB.csv]
2021-01-18 fix some compile errors
    [main.cpp]
2021-01-19 improved calibration UI
2021-01-20 added case
    [encasing.stl]
2021-01-20 added amf
    [encasing.amf, encasing.stl]
2021-01-21 fixed state and ui bugs
    [main.cpp]
2021-01-21 bypassed button bug
2021-01-21 ecansing version 3
    [encasing3.FCStd]
2021-01-21 m5 edges
    [encasing3.FCStd]
2021-01-22 fixed wifi client bug
    [main.cpp]
2021-01-22 remove center screw
    [encasing.amf, encasing3.FCStd]
2021-01-22 next try at a nice case
    [encasing3.FCStd]
2021-01-23 edge for magnet
    [encasing3.FCStd]
2021-01-25 fixed mqtt connection bug
    [main.cpp, main.h]
2021-01-25 fixed guru meditation error
    [main.cpp, main.h]
2021-01-25 fixed not connecting to mqtt after reboot
    [main.cpp]
2021-01-26 fixed disgruence of ui and state
    [main.cpp]
2021-01-27 added home button
2021-01-28 fixed config portal bug
    [main.cpp, main.h]
2021-01-28 fixed password and exit issue
    [main.cpp, main.h]
2021-01-28 now resetting all SSIDs
    [main.cpp]
2021-01-29 fix some nasty error messages
    [main.cpp]
2021-01-29 fixed wrong access point starts
    [main.cpp, main.h]
2021-02-01 device name now changes after a reset
    [main.cpp]
2021-02-01 added state machine to avoid blocking while connecting to wifi
    [main.cpp, main.h]
2021-02-02 fixed timing in state machine
    [main.cpp, main.h]
2021-02-03 fixed config portal bugs
    [main.cpp]
2021-02-09 added stl for case
    [encasing3.stl, encasing3_smoca_body.stl, encasing3_smoca_color.stl]
2021-08-24 fixed calibration title
2021-11-18 Update co2-sensor/platformio.ini, Readme.md
2022-01-05 added de manual
2022-01-05 fixed rtc and removed unused dependencies
    [main.cpp, main.h]
2022-01-05 fix wifi on / off button
    [main.cpp]
2022-01-06 fixed password to be always saved as 1 in state
    [main.cpp]
2022-12-23 Fix type errors in mqtt.publish
    [main.cpp]
2022-12-28 Change usage of Arduino strings to char inside config structs
2022-12-30 Replace strncpy/strcpy with strlcpy
    [main.cpp]
2022-12-30 Replace direct call of strlcpy with dynamic size macro
    [main.cpp, main.h]
2024-05-31 smal fixes
    [encasing3-Cut.3mf]
2024-06-03 added custom pcb design
    [bf-021.kicad_pcb, bf-021.kicad_sch]
2024-06-04 check which sensor
2024-06-04 improved design
    [bf-021.kicad_pcb, bf-021.kicad_sch]
2024-06-19 fixed connector being on wrong side
    [bf-021.kicad_pcb]
2024-07-02 base encasing4
    [encasing4.FCStd]
2024-07-02 holes for screws
    [encasing4.FCStd]
2024-07-02 cut grid
    [encasing4.FCStd]
2024-07-02 stl file
    [encasing4-Cut.stl]
2024-07-03 schraubengewinde, magnetanpassung
    [encasing4-Cut.stl, encasing4.FCStd]
2024-07-04 magnetloch tiefer
    [encasing4-Cut.3mf, encasing4.FCStd]

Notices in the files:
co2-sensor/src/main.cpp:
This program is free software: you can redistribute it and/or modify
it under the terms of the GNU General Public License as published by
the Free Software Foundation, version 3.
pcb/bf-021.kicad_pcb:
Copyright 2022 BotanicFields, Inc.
